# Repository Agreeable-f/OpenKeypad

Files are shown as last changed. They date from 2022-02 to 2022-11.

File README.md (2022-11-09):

# OpenKeypad
## What is it?
 An open source and fully customizable keypad for osu. (based on the arduino pro micro and it's atmega32u4 chip.)  

# General information stuff for how to do everything

## TLDR/shorter version and FAQ at the end:  

# Print info/settings:

### NOTE: LID MUST BE FLIPPED 180° ON THE X OR Y AXIS SUCH THAT IT LAYS FLAT.

All prototypes and models were printed on a prusa i3mk2s.
.2mm layer height with 3 top and bottom solid layers and 4 perimiter/shells.
first layer height is set to 200% with the first layer width at 100%
Infill was set to 100% With the rectelinear pattern. No supports needed!
more details in the simplify3d profile.

# Pins to solder to and how to change them:
 
Solder your positive pins to 5 and 15 (or what they are defined to in the code)
and the negative pins to any of the GND pins. When doing to ensure that none of the wire 
pokes out of the bottom of the board. You can also solder both negative pins to one GND 
if you want, however both positive pins must be connected to separate pins. 
You can also change what pins you'd like to solder to (with the exception of GND) 
on lines 41-56. Un-comment the pin that you want to solder to/use 
 (remove the // on the left) and change the binding on the left side in the empty ' '.

# How to solder and install Kailh hot swap sockets:

### NOTE:  THICK SIDE (LEFT) GOES TO GROUND AND SKINNY SIDE (RIGHT) GOES TO THE PINOUT (5, 15 EXT.)

Solder the wires to the defined pins in the code (default is 5 and 15) as well as the GND/ground pins
(any will work) I used the pins that came with the board and used them as leads to solder to.
Add a ball of solder to your iron and gently drop it into one of the two metal 
bits on the side of the socket. If the peice melts the plastic and sags down, you
can heat it and push it back up. To solder the wire hold the socket so that it's facing 
bottom up. Solder the wire directly perpendicular to the socket such that it sticks straight 
down (otherwise there will be spacing issues with the walls of the keypad). 

### NOTE: You might have to glue the hotswap sockets down otherwise they might come out when removing the switch. Super glue woks well and is still somewhat removable.
     
# How to change what keys you want bound:

On lines 41-56 in the code you can change each pin to a different letter 
or modifier. To do this, simply add your key/letter in the empty ' ' on the 
corresponding line of the pin you have soldered to.

# How to install the Arduino Pro Micro:
     
If your board has a flange/lip around the port that will need to be clipped
in order for it to fit into the hole. position the board such that the port 
is alligned with the hole at a slight angle. Then push the port gently into the hole
(may use pliars if necessary).once seated press the board down such that it sits in the
lip/border to hold it in place.  
(If it doesn't get held in place or the border broke off somehow, you can glue it down or use a thin double sided tape.)

# How to upload code to the arduino:

Connect the arduino to your pc and select arduino leonardo in the tools drop down menu and install all the required libraries. 
Make sure you selected the right COM port in the tools menu if it's not already selected. Click the upload button and let it finish.

# TLDR;/short and concise version:

Solder wires to pins 5 and 15 (default) and GND/ground. If using hot swap sockets left (thick side) is gnd.
To change the keys/pins change the definitions on lines 41-56. To insert the arduino
line up the port with the hole and push it in and down. then upload the code and you're done.

# FAQ:

Q: Do i have to upload the code every time i plug it in?  
A: Nope! uploading code is a one time thing! (unless it gets updated or needs to be changed)

Q: Can i use this on other computers?  
A: Yes! Just remember to set your binds correctly in osu!.  

Q: What switches can i use?  
A: All gateron style switches are compatible.  
(if you are using v2.5 without hotswap socket support you may have to solder directly to the pins of the switch)

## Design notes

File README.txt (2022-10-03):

Everything was moved to the README.md for better formatting and changes. Please read or skim it before printing.

https://github.com/Agreeable-f/OpenKeypad#readme

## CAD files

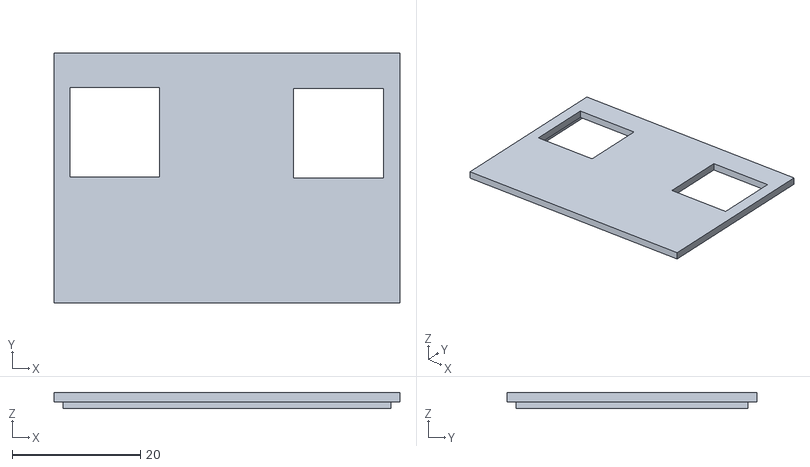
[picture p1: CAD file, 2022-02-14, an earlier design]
V1/1k_gap/lid.stl
54.0 x 39.0 x 2.50

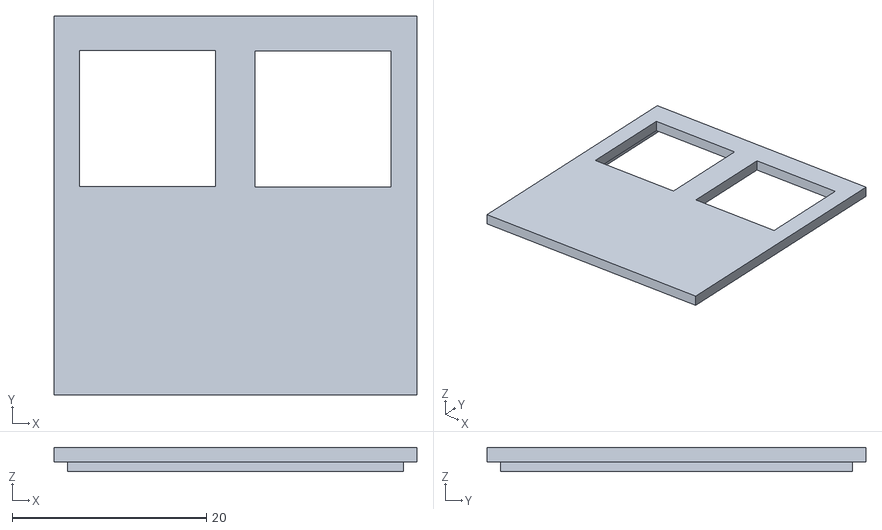
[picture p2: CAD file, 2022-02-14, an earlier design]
V1/no_gap/lid.stl
37.3 x 39.0 x 2.50

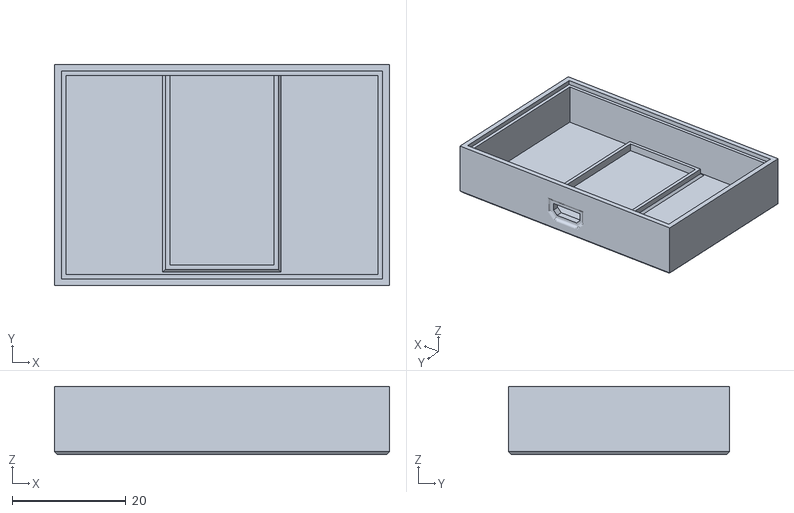
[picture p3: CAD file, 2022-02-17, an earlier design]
v2.5/1k_gap/Case.stl
59.0 x 39.0 x 12.0

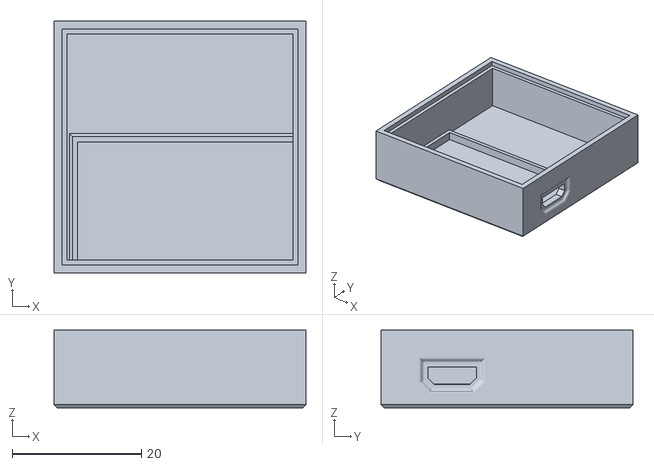
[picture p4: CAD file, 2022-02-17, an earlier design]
v2.5/Nogap/caseR.stl
39.0 x 39.0 x 12.0

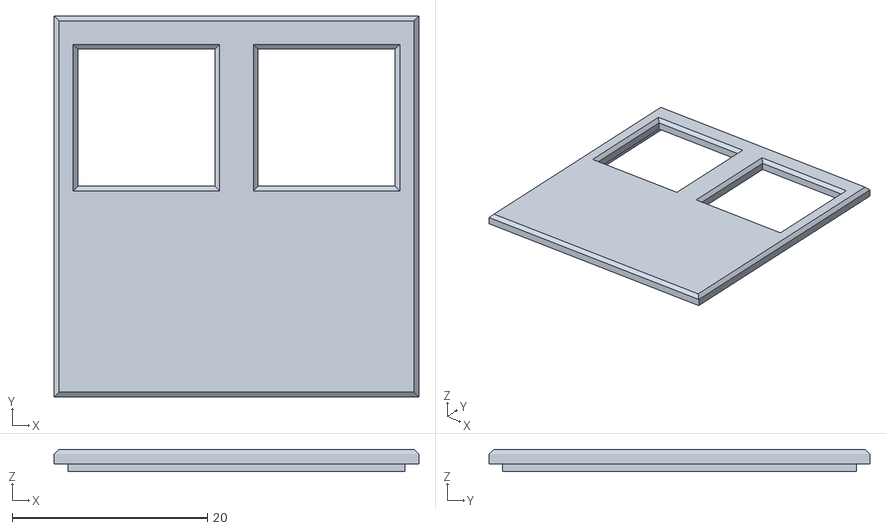
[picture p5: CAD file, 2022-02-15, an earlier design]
V2/NoGap/lid_nogap.stl
37.3 x 39.0 x 2.30

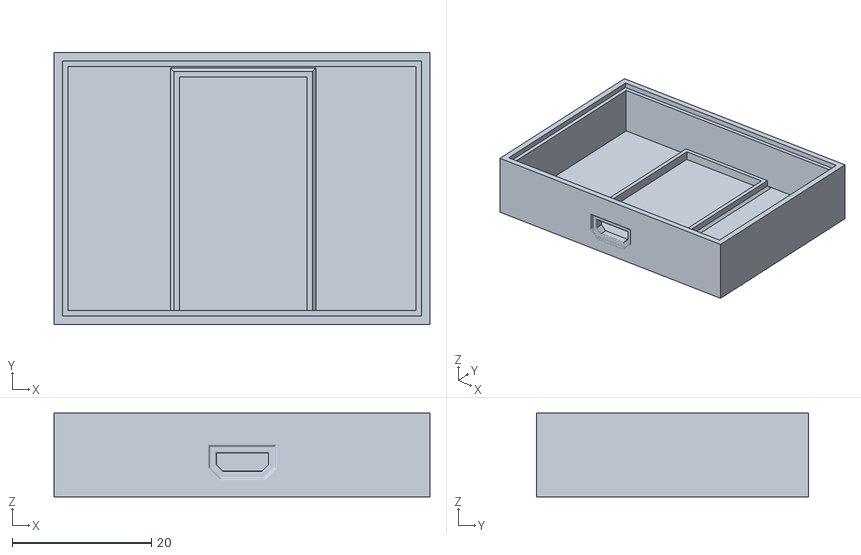
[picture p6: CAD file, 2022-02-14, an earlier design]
V1/1k_gap/housing.stl
54.0 x 39.0 x 12.0

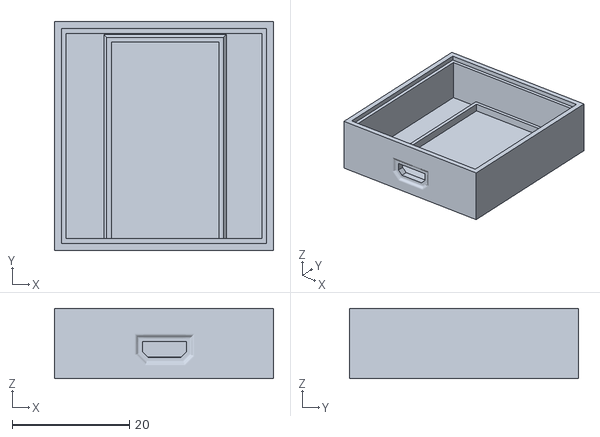
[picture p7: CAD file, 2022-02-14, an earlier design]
V1/no_gap/housing.stl
37.3 x 39.0 x 12.0

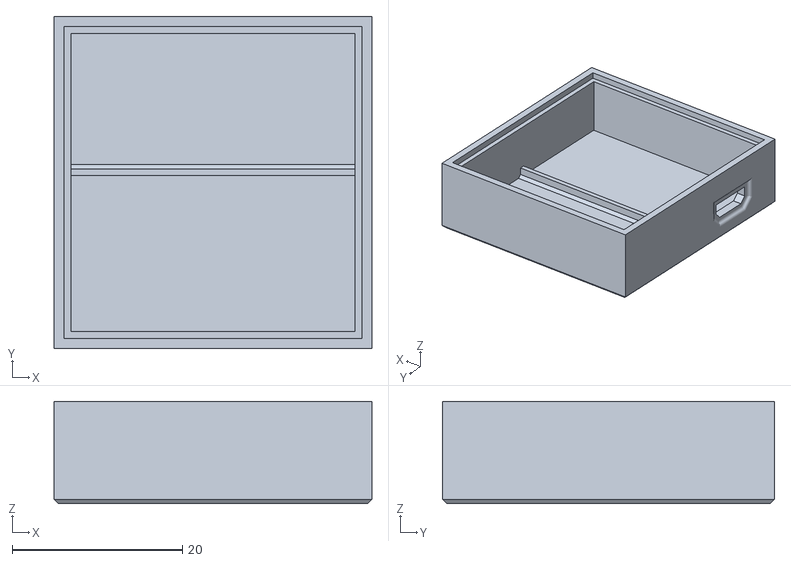
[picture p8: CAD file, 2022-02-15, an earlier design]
V2/NoGap/case_nogap.stl
37.3 x 39.0 x 12.0

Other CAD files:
v2.5/Nogap/caseL.stl
V1/1k_gap/keypad_choc_white_1kgap.f3d
V1/no_gap/keypad_choc_white_nogap.f3d
V2/NoGap/kaypad_nogap_V2.f3d
v2.5/1k_gap/Keypad_1kGap_V2.5.f3d
v2.5/Nogap/Keypad_Nogap_V2.5L.f3d
v2.5/Nogap/Keypad_Nogap_V2.5R.f3d
v3/1kgap/Keypad_1kGap_V3.f3d

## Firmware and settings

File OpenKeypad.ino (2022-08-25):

//Original Code from here(https://bit.ly/3vGVAlB)

//Thanks Sunny for the edits :D

#include "Keyboard.h"
 
// Button helper class for handling press/release and debouncing
class button {
  public:
  const char key;
  const uint8_t pin;
 
  button(uint8_t k, uint8_t p) : key(k), pin(p){}
 
  void press(boolean state){
    if(state == pressed || (millis() - lastPressed  <= debounceTime)){
      return; // Nothing to see here, folks
    }
 
    lastPressed = millis();
 
    state ? Keyboard.press(key) : Keyboard.release(key);    
    pressed = state;
  }
 
  void update(){
    press(!digitalRead(pin));
  }
 
  private:
  const long debounceTime = 30;
  unsigned long lastPressed;
  boolean pressed = 0;
} ;

// Add buttons to this array, in the form { key, pin }
button buttons[] = {
  //{' ', 1},
  //{' ', 2},
  //{' ', 3},
  //{' ', 4},
  {'z', 5},
  {'s', 5},
  {'d', 15},
  //{' ', 16},
  //{' ', 5},
  //{' ', 6},
  //{' ', 7},
  //{' ', 8},
  //{' ', 9},
  //{' ', 10},
  //{' ', 11},
  //{' ', 12},
  //{' ', 13},
  //{' ', 14},
  {'x', 15},
  //{' ', 16},
};
 
const uint8_t NumButtons = sizeof(buttons) / sizeof(button);
const uint8_t ledPin = 17;

// ---------------------------------

void setup() {
   // Safety check. Ground pin #1 (RX) to cancel keyboard inputs.
  pinMode(1, INPUT_PULLUP);
  if(!digitalRead(1)){
    failsafe();
  }
 
  // Set LEDs Off. Active low.
  pinMode(ledPin, OUTPUT);
  digitalWrite(ledPin, HIGH);
  TXLED0;
 
  for(int i = 0; i < NumButtons; i++){
    pinMode(buttons[i].pin, INPUT_PULLUP);
  }
}

void loop() {
 for(int i = 0; i < NumButtons; i++){
    buttons[i].update();
  }
}
 
void failsafe(){
  for(;;){} // Just going to hang out here for awhile :D
}

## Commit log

2022-02-14 V1 (based on kailh choc white)
    original designs for both no spaced variant as well as 1 key spaced variant.
    [housing.stl, keypad_choc_white_1kgap.f3d, keypad_choc_white_nogap.f3d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]
2022-02-15 reorganization
    i moved all the v1 files to a folder called v1 for the sake of organization
    [housing.stl, keypad_choc_white_1kgap.f3d, keypad_choc_white_nogap.f3d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]
2022-02-15 added code
    added the code file for the arduino pro micro
2022-02-15 added stuff.txt
    added a text file called stuff.txt that describes how to use the code and how to solder the switches.
2022-02-15 added v2 nogap
    i reworked the nogap version of the keypad.
    [case_nogap.stl, lid_nogap.stl]
2022-02-15 added f360 file for v2 nogap
    added f360 file for v2 nogap
    [kaypad_nogap_V2.f3d]
2022-02-17 organization and 2.5
    organized the files and versions a little more and added v2.5
    [Keypad_Nogap_V2.5L.f3d, Keypad_Nogap_V2.5R.f3d, caseL.stl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]
2022-02-17 reworked 1k gap
    reworked 1k gap to be up to v2.5 tolerances and proper spacing for a 1 key gap
    [Case.stl, Keypad_1kGap_V2.5.f3d, lid.stl]
2022-02-17 added s3d profile
    added the simplify 3d profile and updated README with print settings
2022-02-17 fixed 1kgap model
    turns out the spacing of the key holes was slightly off so i fixed it
    [Case.stl, Keypad_1kGap_V2.5.f3d, lid.stl]
2022-02-17 added v3
    finally added v3 with all the fusion files to boot
    [Case.stl, Keypad_1kGap_V3.f3d, caseL.stl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]
2022-02-25 added V4
    added the updated v4 with added auxiliary button support
    [Case.stl, Keypad_1kGap_V4.f3d, caseL.stl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]
2022-04-08 Simplify buttons configuration
2022-05-27 moving in sunny edit
    moves in sunny's edit of simplifying button definitions
2022-10-04 removed redundant v4 directory
    removed redundant v4 directory until i have some things to actually put in there for the next release
    [Case.stl, Keypad_1kGap_V4.f3d, caseL.stl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]
